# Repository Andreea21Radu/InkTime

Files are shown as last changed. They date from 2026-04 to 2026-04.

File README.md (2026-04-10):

# InkTime - Smartwatch PCB Design

**Autor:** Radu Andreea
**Licenta:** Apache License 2.0 

## 1. Arhitectura sistemului

Sistemul este construit in jurul microcontroller-ului **nRF52840**, care gestioneaza comunicatia si perifericele.

Structura generala este urmatoarea:

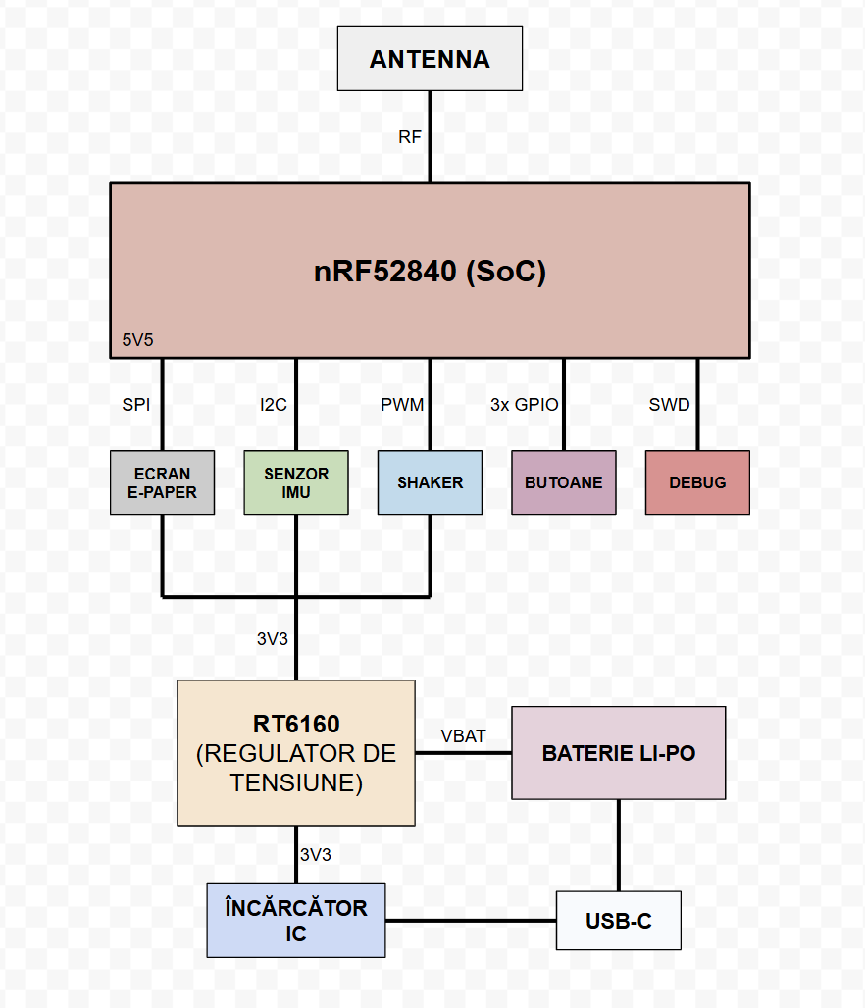
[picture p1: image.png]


## 2. BOM (Bill of Materials)

## CIRCUITE INTEGRATE (IC)

| Componentă | JLC Part # | Package | Descriere | Datasheet |
| :--- | :--- | :--- | :--- | :--- |
| IC1 | C3682423 | DSBGA-8 (1.6x1.1) | Încărcător baterie Li-Ion / Li-Polymer | [datasheet](https://www.ti.com/cn/lit/ds/symlink/bq25180.pdf) |
| IC2 | C81079 | DSBGA-9 | Driver haptic ERM/LRA | [datasheet](https://www.ti.com/cn/lit/gpn/drv2605) |
| IC3 | C189517 | LGA-12 (2x2) | Accelerometru 3 axe low-g 12bit | [datasheet](https://www.lcsc.com/datasheet/C189517.pdf) |
| IC9 | C7065276 | WLCSP-15B (2.3x1.4) | DC-DC buck-boost regulator I2C | [datasheet](https://wmsc.lcsc.com/wmsc/upload/file/pdf/v2/lcsc/2312271436_Richtek-Tech-RT6160AWSC_C7065276.pdf) |
| U1 | C3606653 | QFN-48 (6x6) | nRF52840 MCU | [datasheet](https://www.lcsc.com/datasheet/C3606653.pdf) |
| U2 | C2682616 | DFN-8-EP (2x2) | Fuel gauge baterie Li-Ion I2C | [datasheet](https://www.lcsc.com/datasheet/lcsc_datasheet_2410121738_Analog-Devices-Inc--Maxim-Integrated-MAX17048G-T10_C2682616.pdf) |

---

## CONECTORI

| Componentă | JLC Part # | Package | Descriere | Datasheet |
| :--- | :--- | :--- | :--- | :--- |
| J1 | C122434 | SMD, FFC/FPC 0.5mm | Conector FPC 24 pini, unghi drept | [datasheet](https://www.molex.com/content/dam/molex/molex-dot-com/products/automated/en-us/salesdrawingpdf/503/503480/5034802400_sd.pdf) |
| J2 | C90533 | 1mm pitch | Adaptor cablu 6 poziții | [datasheet](https://wmsc.lcsc.com/wmsc/upload/file/pdf/v2/lcsc/1810141506_LX-FFC6P1-0mm7CM_C90533.pdf) |
| J4 | C709357 | USB-C SMD | Conector USB Type-C 16P | [datasheet](https://www.lcsc.com/datasheet/lcsc_datasheet_2404191039_Shenzhen-Kinghelm-Elec-KH-TYPE-C-16P_C709357.pdf) |

---

## SEMICONDUCTORI

| Componentă | JLC Part # | Package | Descriere | Datasheet |
| :--- | :--- | :--- | :--- | :--- |
| Q1 | C2564 | TO-220AB | MOSFET P-channel 55V 74A | [datasheet](https://www.lcsc.com/datasheet/lcsc_datasheet_1809041724_Infineon-Technologies-IRF4905PBF_C2564.pdf) |
| Q3 | C469327 | SOT-323 | MOSFET N-channel 30V 1.5A | [datasheet](https://www.lcsc.com/datasheet/lcsc_datasheet_1912202016_Vishay-Intertech-SI1308EDL-T1-GE3_C469327.pdf) |
| D2, D4, D5 | C82046 | SOD-123 | Diodă Schottky 0.5A 30V | [datasheet](https://www.lcsc.com/datasheet/lcsc_datasheet_2304140030_onsemi-MBR0530T1G_C82046.pdf) |
| D3 | C2969755 | SOT-23-6L | Protecție ESD USB | [datasheet](https://wmsc.lcsc.com/wmsc/upload/file/pdf/v2/lcsc/2211080730_STMicroelectronics-USBLC6-2SC6Y_C2969755.pdf) |

---

## INDUCTORI

| Componentă | JLC Part # | Package | Descriere | Datasheet |
| :--- | :--- | :--- | :--- | :--- |
| L1, L2, L3 | C12669 | 0402 | Inductor general (chip inductor) | [datasheet](https://www.lcsc.com/datasheet/lcsc_datasheet_2304140030_Murata-Electronics-LQG15HS27NJ02D_C12669.pdf) |
| L5 | C1329646 | SMD 4.8x4.8mm | Power inductor 4.7µH 1.6A | [datasheet](https://wmsc.lcsc.com/wmsc/upload/file/pdf/v2/lcsc/2304140030_BOURNS-SRR4828A-4R7Y_C1329646.pdf) |
| L7 | C5832368 | 1008 | Power inductor 470nH 6.5A | [datasheet](https://wmsc.lcsc.com/wmsc/upload/file/pdf/v2/lcsc/2306021632_cjiang--Changjiang-Microelectronics-Tech-FTC252012SR47MBCA_C5832368.pdf) |

---

## CRISTALE

| Componentă | JLC Part # | Package | Descriere | Datasheet |
| :--- | :--- | :--- | :--- | :--- |
| X1 | C9009 | SMD3225-4P | Cristal Oscilator 32 MHz | [datasheet](https://www.lcsc.com/datasheet/lcsc_datasheet_2403291504_YXC-Crystal-Oscillators-X322532MOB4SI_C9009.pdf) |
| X2 | C32346 | SMD3215-2P | Cristal Oscilator 32.768 kHz | [datasheet](https://www.lcsc.com/datasheet/lcsc_datasheet_2404180925_Seiko-Epson-Q13FC13500004_C32346.pdf) |

---

## REZISTOARE

| Componentă | JLC Part # | Package | Descriere | Datasheet |
| :--- | :--- | :--- | :--- | :--- |
| R1_EP_DR | C3920633 | 0201 | 7.68kΩ Thin Film ±0.5% | [datasheet](https://wmsc.lcsc.com/wmsc/upload/file/pdf/v2/lcsc/2404081048_TE-Connectivity-CPF0201B511RE1_C3920633.pdf) |
| R1_USB, R2_USB | C3920633 | 0201 | 7.68kΩ Thin Film ±0.5% | [datasheet](https://wmsc.lcsc.com/wmsc/upload/file/pdf/v2/lcsc/2404081048_TE-Connectivity-CPF0201B511RE1_C3920633.pdf) |
| R2, R3, R4 | C3920633 | 0201 | 7.68kΩ Thin Film ±0.5% | [datasheet](https://wmsc.lcsc.com/wmsc/upload/file/pdf/v2/lcsc/2404081048_TE-Connectivity-CPF0201B511RE1_C3920633.pdf) |
| R2_EP_DR, R9, R_PWR_EPD | C3920633 | 0201 | 7.68kΩ Thin Film ±0.5% | [datasheet](https://wmsc.lcsc.com/wmsc/upload/file/pdf/v2/lcsc/2404081048_TE-Connectivity-CPF0201B511RE1_C3920633.pdf) |
| R5, R7, R8 | C3920633 | 0201 | 7.68kΩ Thin Film ±0.5% | [datasheet](https://wmsc.lcsc.com/wmsc/upload/file/pdf/v2/lcsc/2404081048_TE-Connectivity-CPF0201B511RE1_C3920633.pdf) |
| R17, R18 | C3920633 | 0201 | 7.68kΩ Thin Film ±0.5% | [datasheet](https://wmsc.lcsc.com/wmsc/upload/file/pdf/v2/lcsc/2404081048_TE-Connectivity-CPF0201B511RE1_C3920633.pdf) |
| R_TYPE_SEL | C3920633 | 0201 | 7.68kΩ Thin Film ±0.5% | [datasheet](https://wmsc.lcsc.com/wmsc/upload/file/pdf/v2/lcsc/2404081048_TE-Connectivity-CPF0201B511RE1_C3920633.pdf) |

---

## CAPACITORI

| Componentă | JLC Part # | Package | Descriere | Datasheet |
| :--- | :--- | :--- | :--- | :--- |
| C1, C2, C17, C18 | C9900156064 | 0201 | Generic chip capacitor | [datasheet](https://ds.yuden.co.jp/TYCOMPAS/or/download?pn=MLAST063SCG681JFNA01&fileType=CA) |
| C1-EP-DR | C9900156064 | 0201 | Generic chip capacitor | [datasheet](https://ds.yuden.co.jp/TYCOMPAS/or/download?pn=MLAST063SCG681JFNA01&fileType=CA) |
| C2-EP-DR | C9900156064 | 0201 | Generic chip capacitor | [datasheet](https://ds.yuden.co.jp/TYCOMPAS/or/download?pn=MLAST063SCG681JFNA01&fileType=CA) |
| C3, C4 | C9900156064 | 0201 | Generic chip capacitor | [datasheet](https://ds.yuden.co.jp/TYCOMPAS/or/download?pn=MLAST063SCG681JFNA01&fileType=CA) |
| C5, C7, C8, C12, C19 | C9900156064 | 0201 | Generic chip capacitor | [datasheet](https://ds.yuden.co.jp/TYCOMPAS/or/download?pn=MLAST063SCG681JFNA01&fileType=CA) |
| C6, C14, C20, C21 | C9900156064 | 0201 | Generic chip capacitor | [datasheet](https://ds.yuden.co.jp/TYCOMPAS/or/download?pn=MLAST063SCG681JFNA01&fileType=CA) |
| C9 | C9900156064 | 0201 | Generic chip capacitor | [datasheet](https://ds.yuden.co.jp/TYCOMPAS/or/download?pn=MLAST063SCG681JFNA01&fileType=CA) |
| C10, C13, C22 | C9900156064 | 0201 | Generic chip capacitor | [datasheet](https://ds.yuden.co.jp/TYCOMPAS/or/download?pn=MLAST063SCG681JFNA01&fileType=CA) |
| C11 | C9900156064 | 0201 | Generic chip capacitor | [datasheet](https://ds.yuden.co.jp/TYCOMPAS/or/download?pn=MLAST063SCG681JFNA01&fileType=CA) |
| C15 | C9900156064 | 0201 | Generic chip capacitor | [datasheet](https://ds.yuden.co.jp/TYCOMPAS/or/download?pn=MLAST063SCG681JFNA01&fileType=CA) |
| C16 | C9900156064 | 0201 | Generic chip capacitor | [datasheet](https://ds.yuden.co.jp/TYCOMPAS/or/download?pn=MLAST063SCG681JFNA01&fileType=CA) |
| C23, C27, C34, C42 | C21012218 | 0402 | Capacitor ceramic | [datasheet](https://jlc-prod-smt.oss-eu-central-1.aliyuncs.com/smtDataManualFile/8603520985945550848-C21012218.pdf) |
| C24, C39 | C9900179830 | 0402 | Capacitor ceramic | N/A |
| C25, C33 | C9900179830 | 0402 | Capacitor ceramic | N/A |
| C29, C30, C31, C32, C37, C38 | C3920633 | 0201 | Capacitor ceramic | [datasheet](https://ds.yuden.co.jp/TYCOMPAS/or/download?pn=MLAST063SCG681JFNA01&fileType=CA) |
| C43 | C9900156064 | 0201 | Generic chip capacitor | [datasheet](https://ds.yuden.co.jp/TYCOMPAS/or/download?pn=MLAST063SCG681JFNA01&fileType=CA) |
| EPD_C1, EPD_C2, EPD_C6, EPD_C7, EPD_C8, EPD_C9, EPD_C10, EPD_C11, EPD_C12 | C9900156064 | 0201 | Generic chip capacitor | [datasheet](https://ds.yuden.co.jp/TYCOMPAS/or/download?pn=MLAST063SCG681JFNA01&fileType=CA) |
| EPD_C5 | C9900156064 | 0201 | Generic chip capacitor | [datasheet](https://ds.yuden.co.jp/TYCOMPAS/or/download?pn=MLAST063SCG681JFNA01&fileType=CA) |

---

## ALTE COMPONENTE

| Componentă | JLC Part # | Package | Descriere | Datasheet |
| :--- | :--- | :--- | :--- | :--- |
| ANT1 | C2917717 | 1206 | Antenă Patch 2.4 GHz | [datasheet](https://www.lcsc.com/datasheet/lcsc_datasheet_2404021210_Johanson-Dielectrics-2450AT18B100E_C2917717.pdf) |
| SJ1 | N/A | Solder Jumper | SMD solder JUMPER (leave open) | N/A |
| SW_DN, SW_ENT, SW_UP | C569760 | SMD 3.9x2.9mm | Buton tactil SPST (Tactile Switch) | [datasheet](https://wmsc.lcsc.com/wmsc/upload/file/pdf/v2/lcsc/2301111010_PANASONIC-EVPAKE31A_C569760.pdf) |
| TP (Test Pads) | N/A | N/A | Puncte de testare (Test pads) | N/A |

## 3. Functionalitate hardware si specificatii tehnice

Proiectul **InkTime** reprezinta un dispozitiv wearable optimizat pentru consum redus de energie, capabil sa functioneze pe perioade lungi de timp datorita combinatiei dintre un microcontroller eficient si un display E-Ink, care consuma energie doar la actualizare.

---

### 3.1 Unitatea centrala (Microcontroller)

In centrul sistemului se afla circuitul **nRF52840**, care integreaza toate functiile principale:

* Procesor **ARM Cortex-M4F la 64 MHz**, suficient pentru procesare de semnale si control periferice
* Suport integrat pentru **Bluetooth Low Energy (BLE)**, utilizat pentru comunicarea cu telefonul
* Moduri de consum redus (sleep si deep sleep), unde curentul scade pana la nivel de microamperi

Acest microcontroller permite rularea simultana a comunicatiei wireless si a interactiunii cu senzorii, mentinand consumul scazut.

### 3.2 Sistem de alimentare

Alimentarea este realizata printr-un lant complet de power management:

* **BQ25180** – responsabil pentru incarcarea bateriei Li-Po prin USB-C, folosind metoda CC/CV si protectii integrate
* **RT6160** – convertor buck-boost care asigura o tensiune stabila de **3.3V**, chiar daca bateria scade sub aceasta valoare
* **MAX17048** – circuit de monitorizare a bateriei, care transmite starea de incarcare catre microcontroller prin I2C

Avantajul folosirii convertorului buck-boost este utilizarea eficienta a bateriei pe intreaga plaja de tensiuni.

### 3.3 Comunicatia intre module

Pentru conectarea componentelor, sistemul foloseste doua interfete principale:

#### Magistrala I2C

Este utilizata pentru perifericele inteligente:

* accelerometrul (IMU)
* fuel gauge-ul
* driverul haptic

Toate aceste componente sunt conectate pe aceeasi magistrala, ceea ce reduce numarul de pini folositi si simplifica traseele pe PCB.

#### Magistrala SPI

Este dedicata exclusiv display-ului:

* display-ul E-Ink este conectat prin SPI folosind conectorul FPC
* aceasta interfata permite transfer rapid de date necesar actualizarii imaginii

### 3.4 Interactiune cu utilizatorul

Dispozitivul include:

* 3 butoane pentru navigare (UP, ENTER, DOWN)
* feedback haptic realizat cu **DRV2605**, controlat prin PWM

Acest sistem permite interactiune intuitiva fara consum mare de energie.

### 3.5 Estimarea consumului de energie

Sistemul este alimentat de o baterie Li-Po de aproximativ **250 mAh**.

Consum estimat:

* Sleep (MCU + BLE): ~35 µA
* Functionare activa (citire senzori): ~120 µA
* Actualizare display: ~25 µA

Curent mediu total:

I_avg ≈ 180 µA = 0.18 mA

### 3.6 Autonomie estimata

Autonomia teoretica:

T = 250 mAh / 0.18 mA ≈ 1380 ore

In conditii reale (BLE, senzori, vibratii):

👉 aproximativ **9 – 14 zile**

## 4. Mapare pini nRF52840

### 4.1 Alocarea pinilor

| Componenta | Semnal | Pin nRF | Directie | Motiv |
| --- | --- | --- | --- | --- |
| Display E-Ink | SCK | P0.11 | Output | Clock SPI |
| Display E-Ink | MOSI | P0.12 | Output | Transfer date |
| Display E-Ink | CS | P0.13 | Output | Selectie dispozitiv  |
| Display E-Ink | DC | P0.14 | Output | Data / Command |
| Display E-Ink | RESET  | P0.15 | Output | Reset hardware |
| Display E-Ink | BUSY | P0.16 | Input | Status display |
| I2C | SDA | P0.26 | I/O | Linie date |
| I2C | SCL | P0.27 | Output | Linie clock |
| Buton UP | GPIO | P1.07 | Input | Navigare |
| Buton ENTER | GPIO | P1.08 | Input | Confirmare |
| Buton DOWN | GPIO | P1.09 | Input | Navigare |
| Motor haptic  | PWM | P1.02 | Output | Control vibratii |
| RT6160 | EN | P0.18 | Output | Activare convertor |
| IMU | INT | P0.25 | Input | Intrerupere hardware |

---

### 4.2 Decizii de design

* **Port 0** a fost folosit pentru interfete rapide (SPI, I2C)
* **Port 1** a fost folosit pentru butoane, pentru a evita interferente
* pinii SPI au fost grupati fizic pentru trasee mai scurte
* magistrala I2C este comuna pentru mai multe dispozitive → economie de pini
* pinii NFC (P0.09, P0.10) au fost evitati pentru extensii viitoare

## 5. Design log si decizii de implementare

### 5.1 Layout PCB

* componentele au fost plasate compact
* traseele de alimentare au fost facute la **0.3 mm**
* traseele de semnal la **0.15 mm**
* zona antenei a fost lasata fara cupru

### 5.2 Probleme si solutii

* componente 0201 → necesare pentru spatiu redus
* routing dificil sub MCU → s-au folosit trasee mai subtiri local
* antena → zona keep-out pentru performanta RF

### 5.3 Integritate semnal

* condensatori de decuplare (100nF) plasati foarte aproape de pini
* GND realizat cu polygon pour pe ambele straturi
* via stitching pentru masa

## 6. Randari si imagini

(Imaginile se gasesc in folderul `Images`)

* vedere PCB top
* vedere PCB bottom
* randare 3D
* vedere explodata

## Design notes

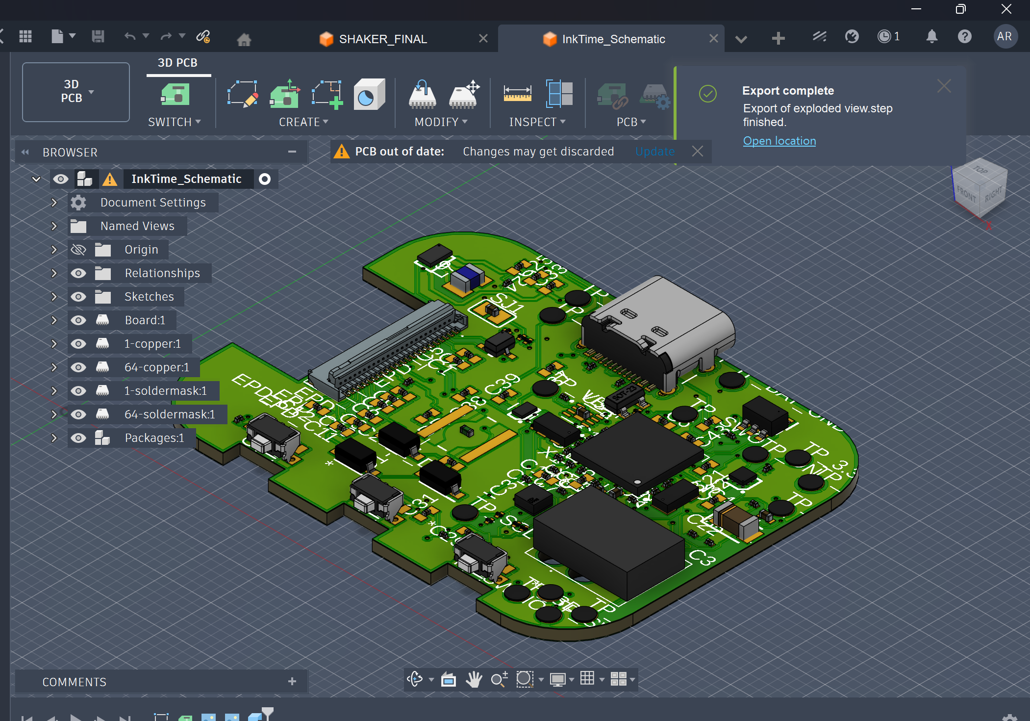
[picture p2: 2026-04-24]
Images/3d.png

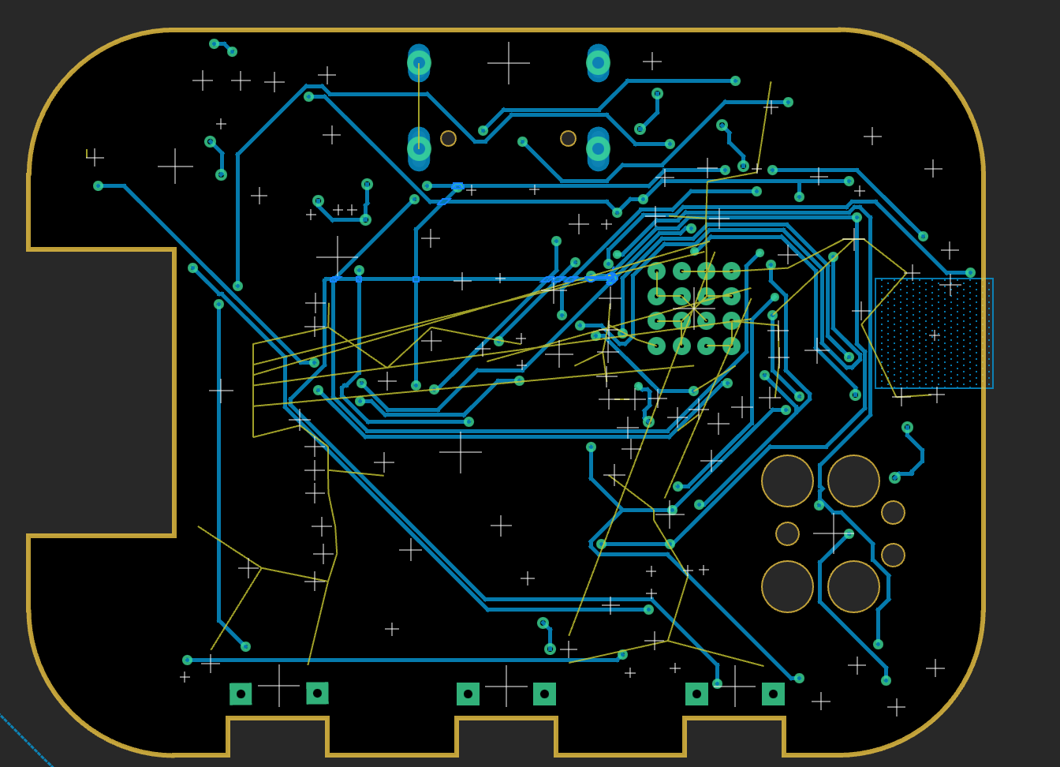
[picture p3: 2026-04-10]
Images/pcb_bottom.png

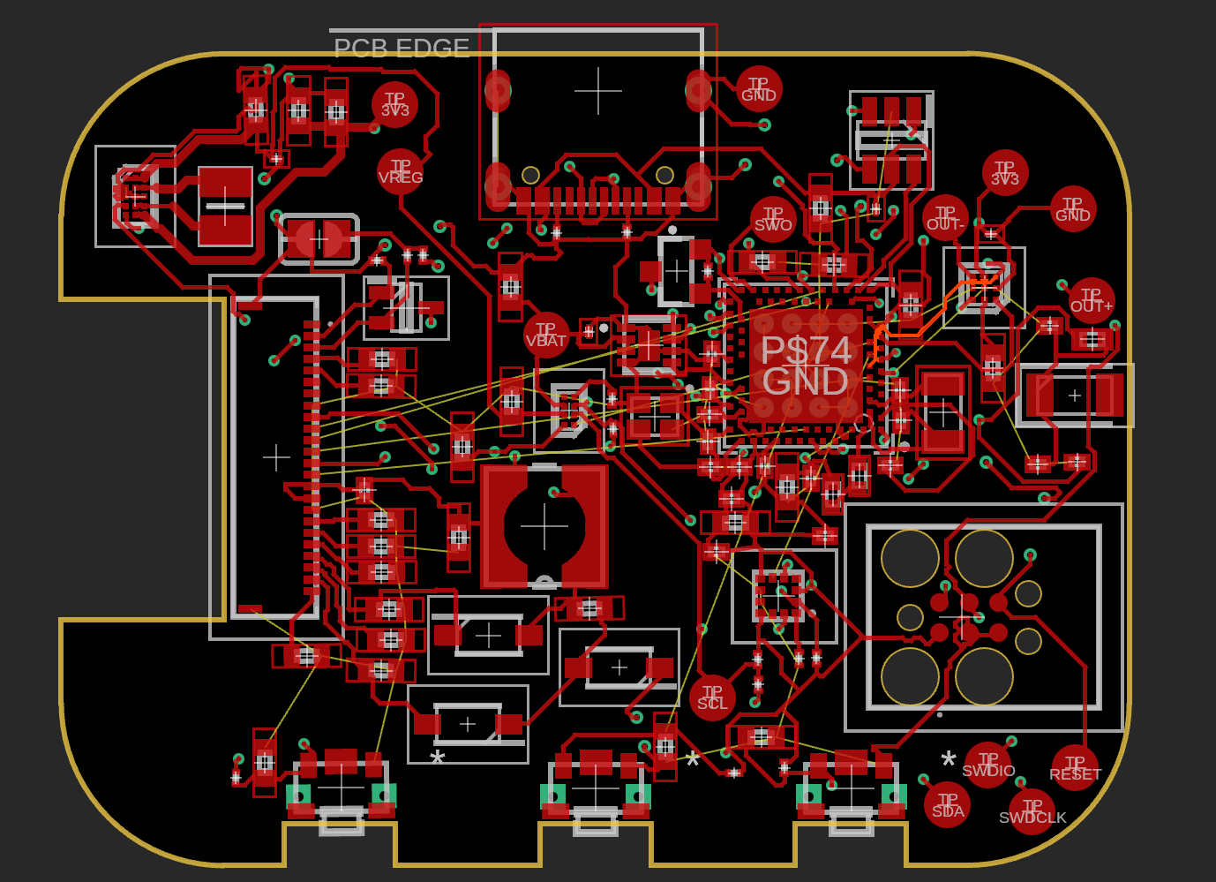
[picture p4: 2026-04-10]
Images/pcb_top.png

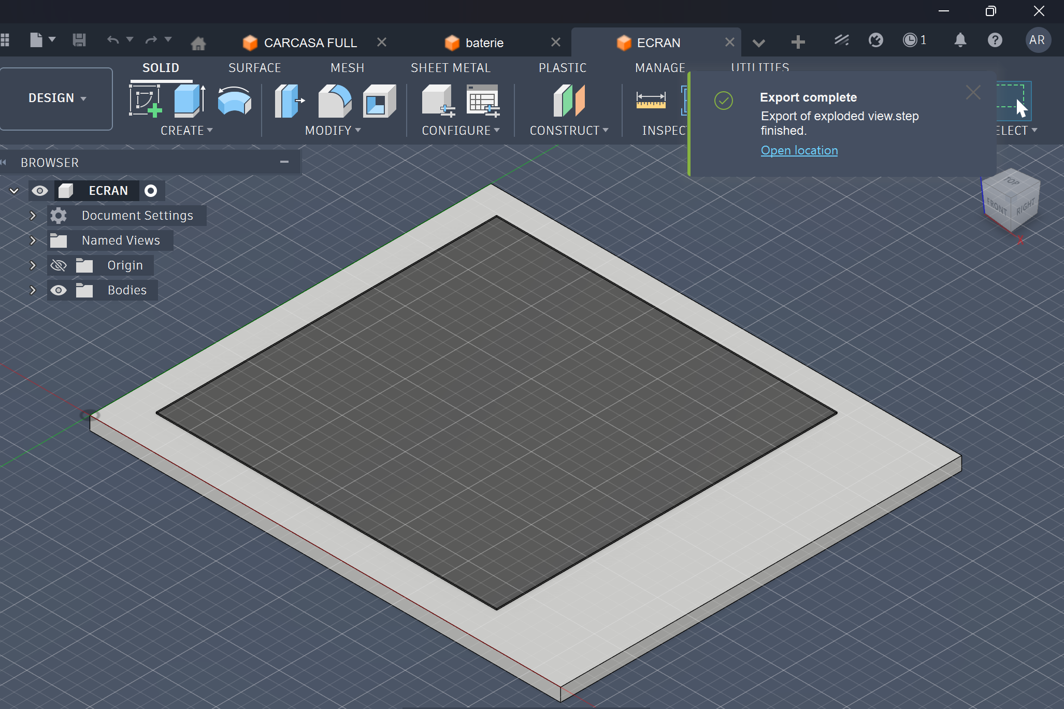
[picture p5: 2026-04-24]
Images/ecran.png

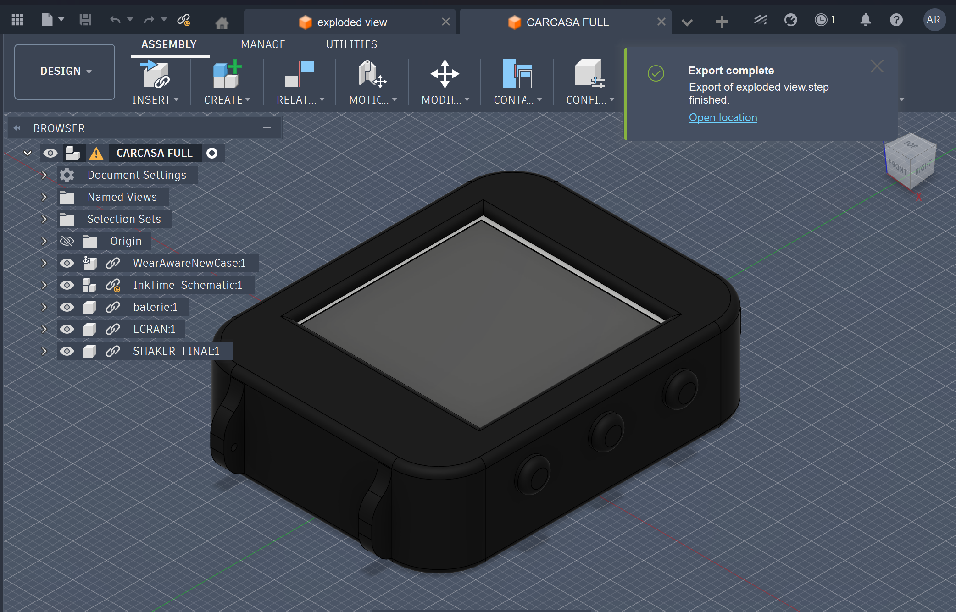
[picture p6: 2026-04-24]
Images/carcasa_full.png

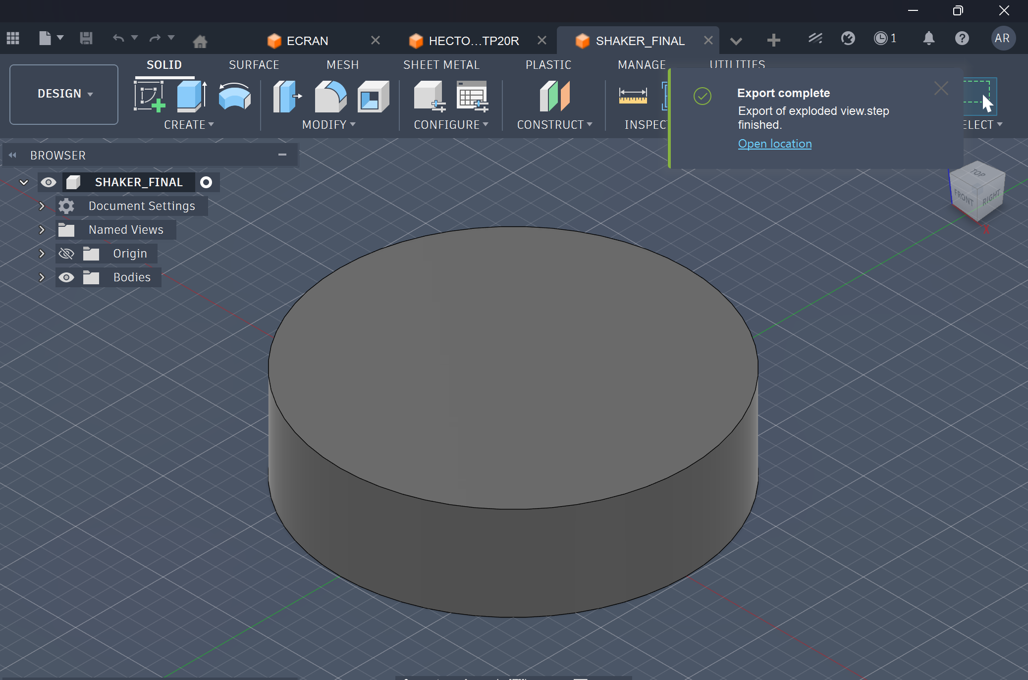
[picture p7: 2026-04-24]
Images/shaker.png

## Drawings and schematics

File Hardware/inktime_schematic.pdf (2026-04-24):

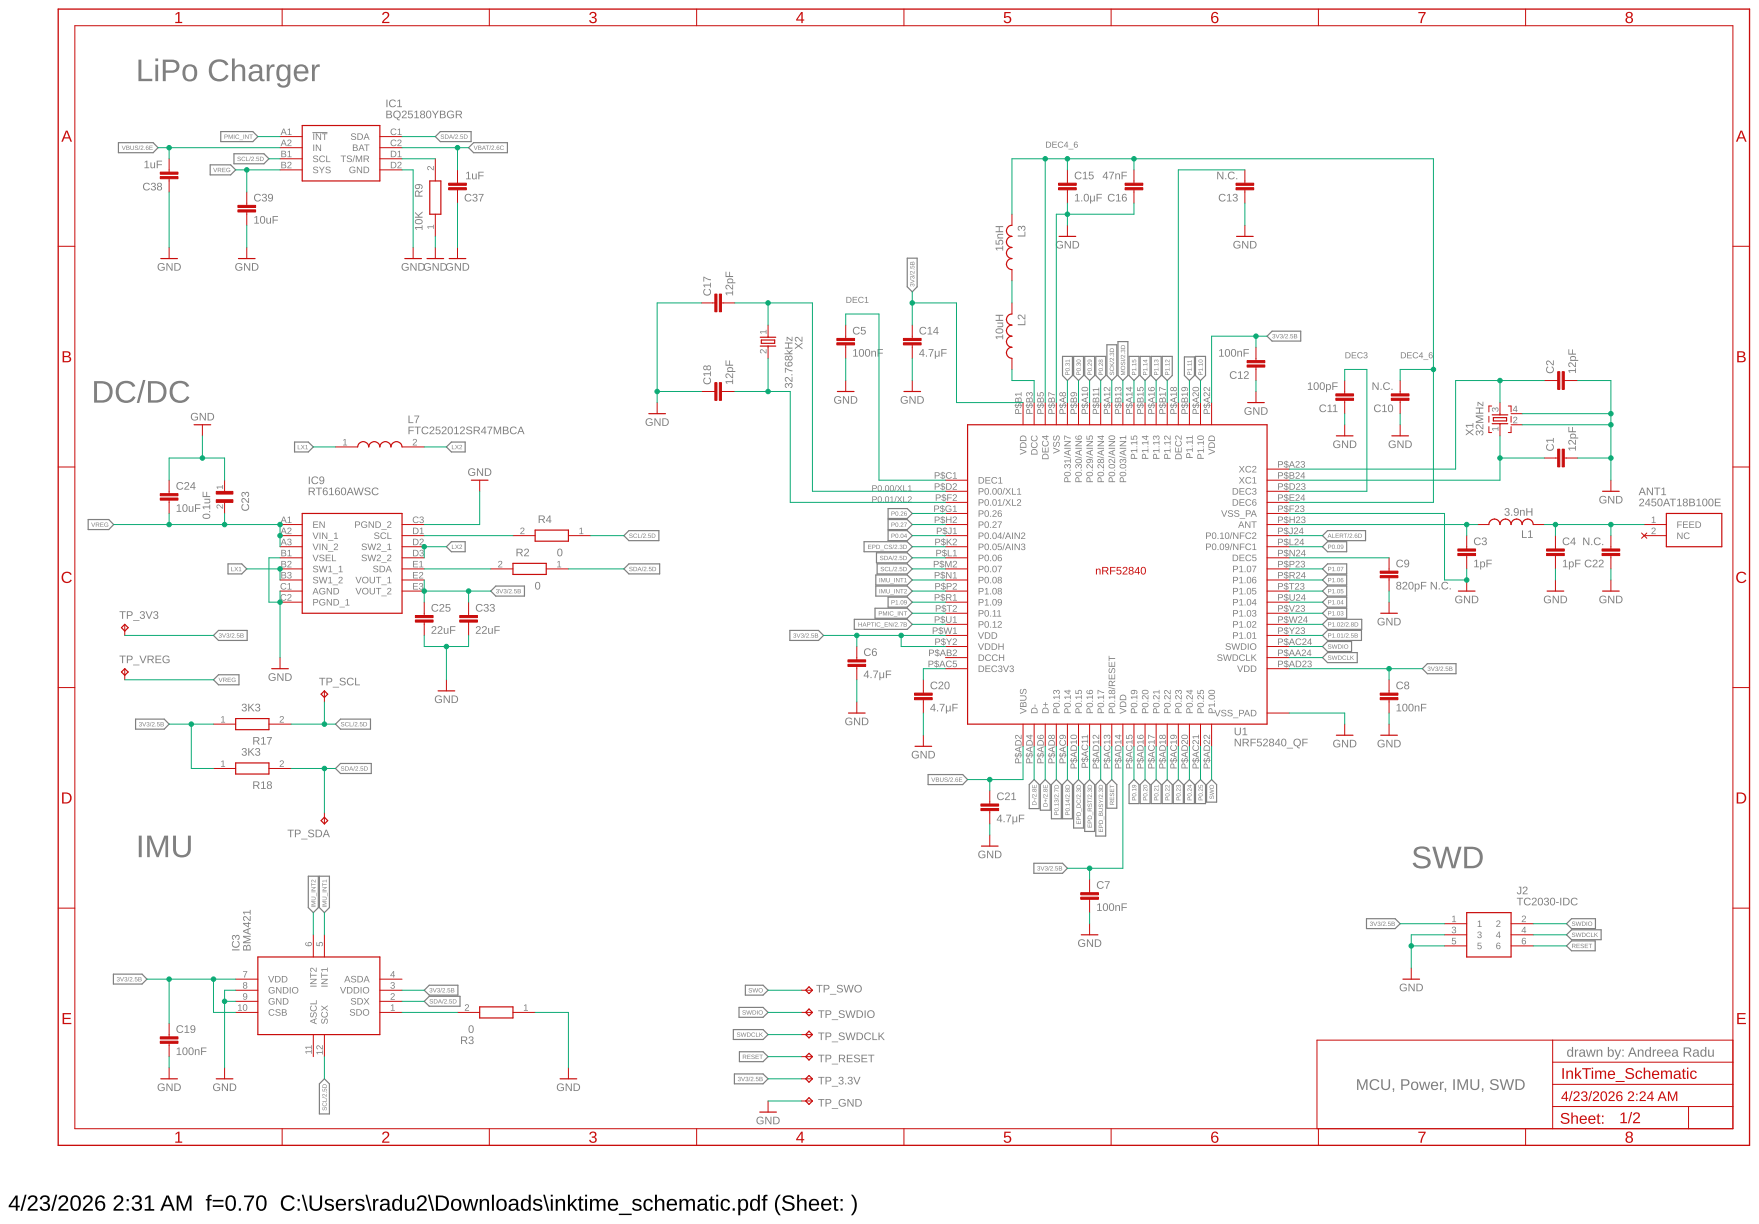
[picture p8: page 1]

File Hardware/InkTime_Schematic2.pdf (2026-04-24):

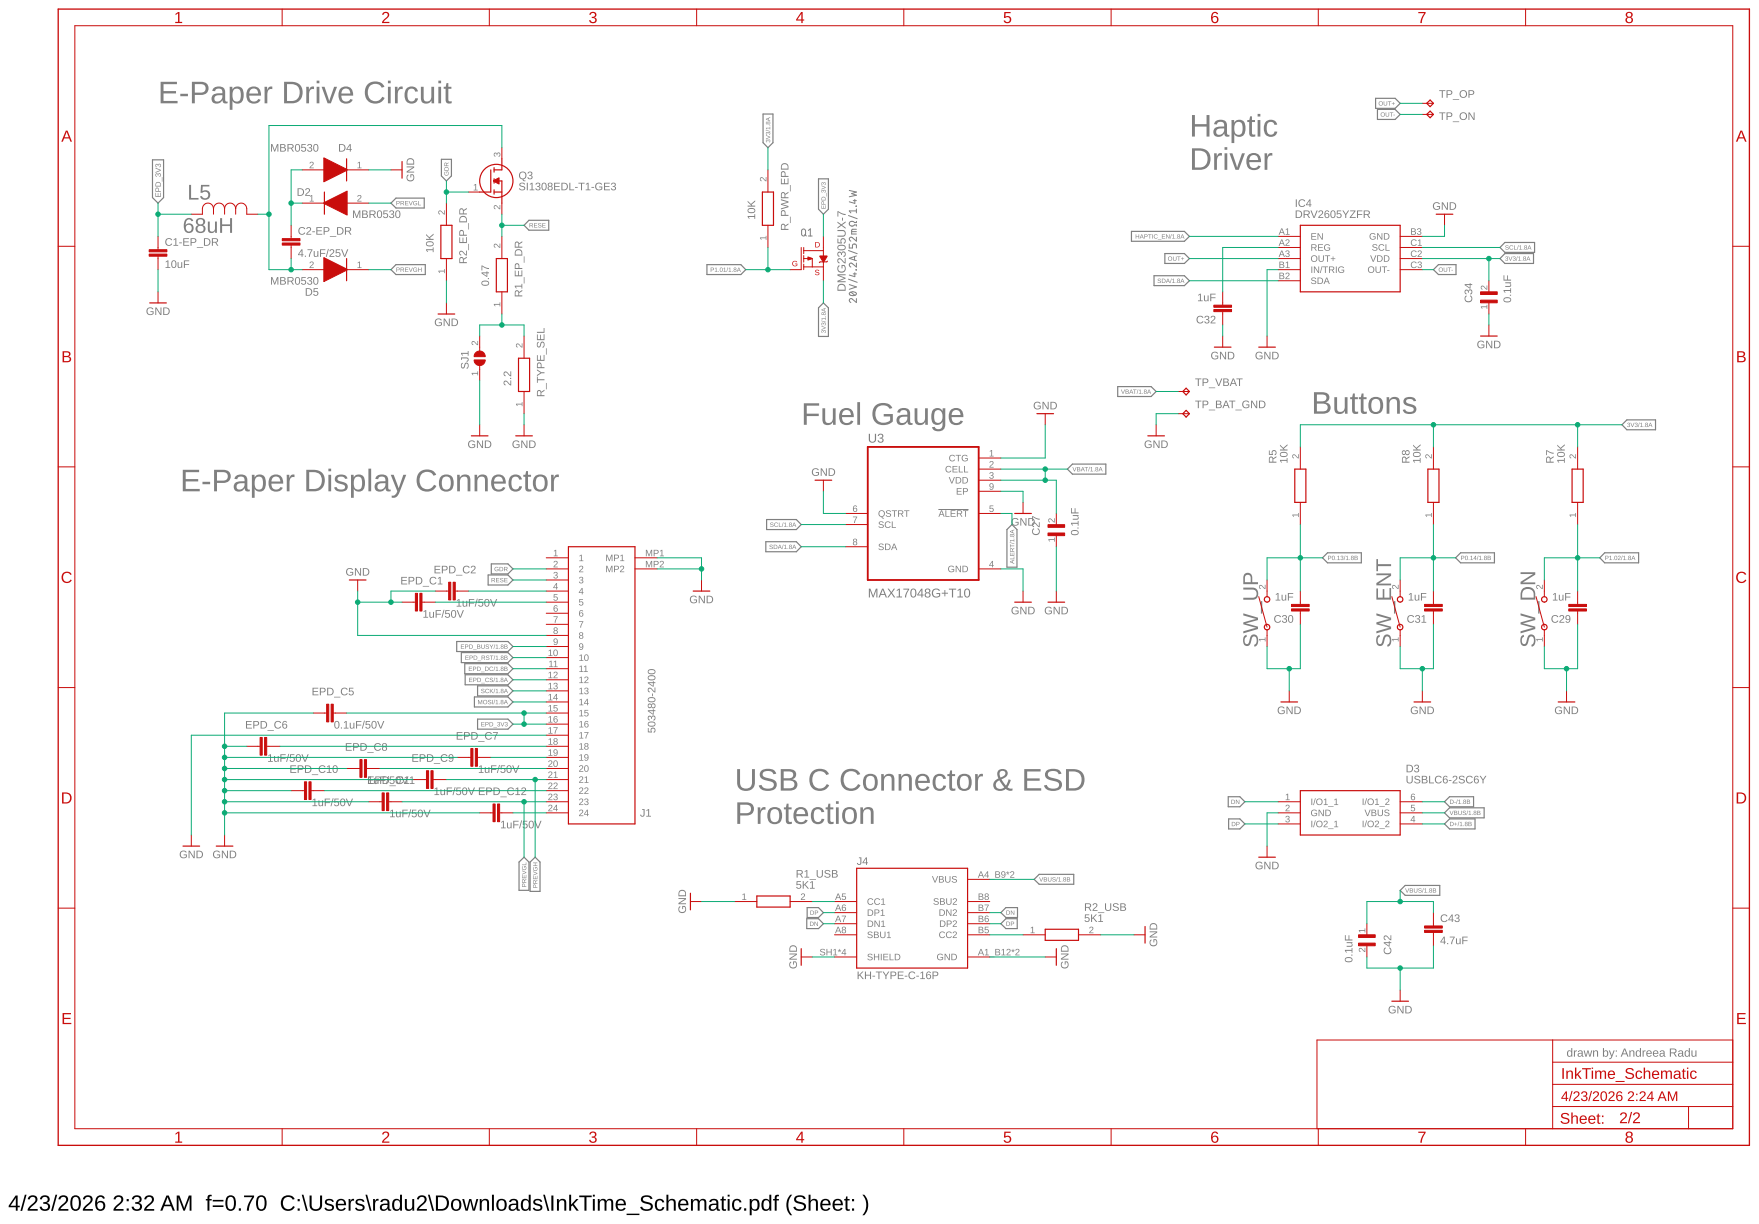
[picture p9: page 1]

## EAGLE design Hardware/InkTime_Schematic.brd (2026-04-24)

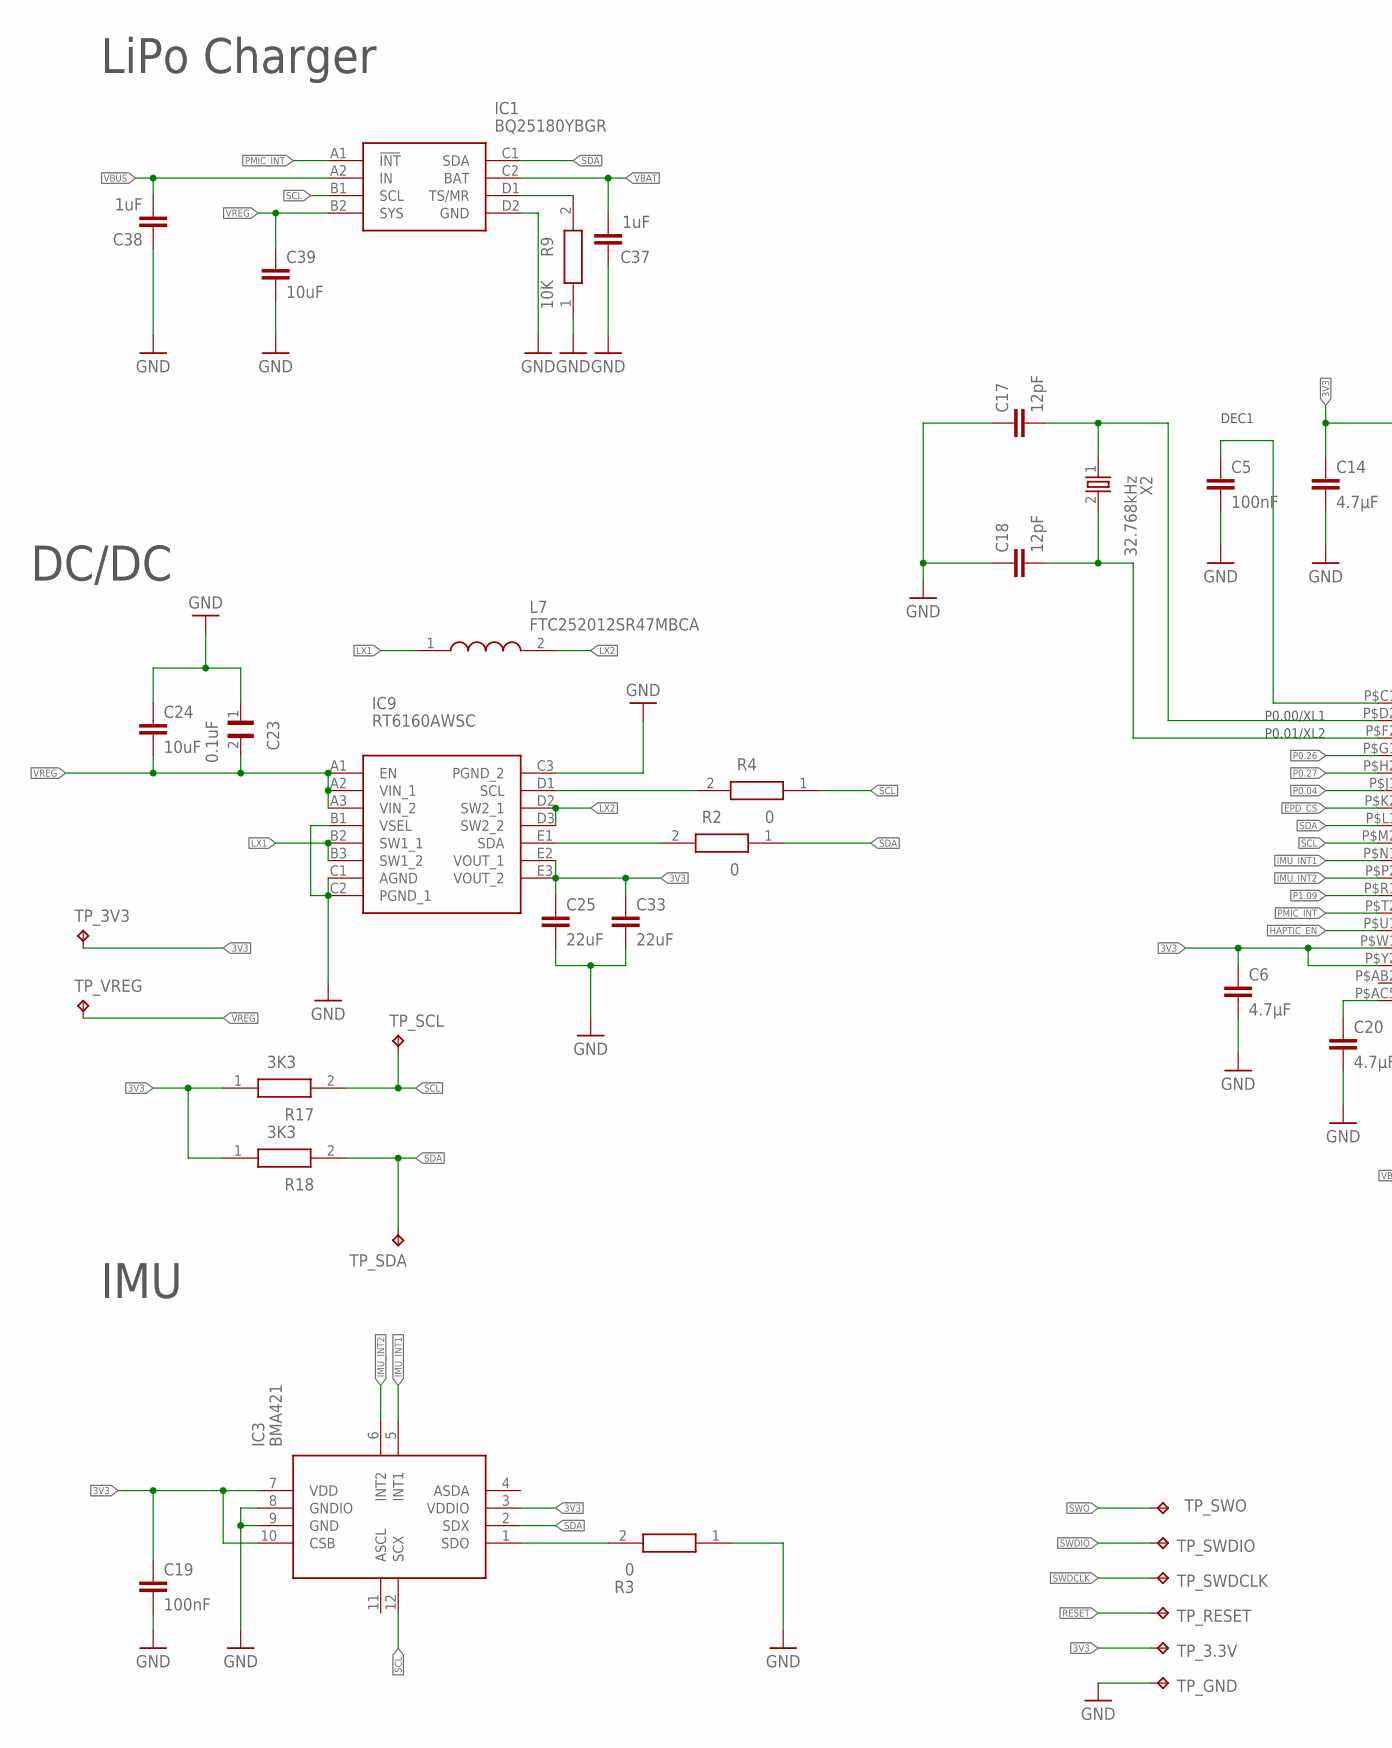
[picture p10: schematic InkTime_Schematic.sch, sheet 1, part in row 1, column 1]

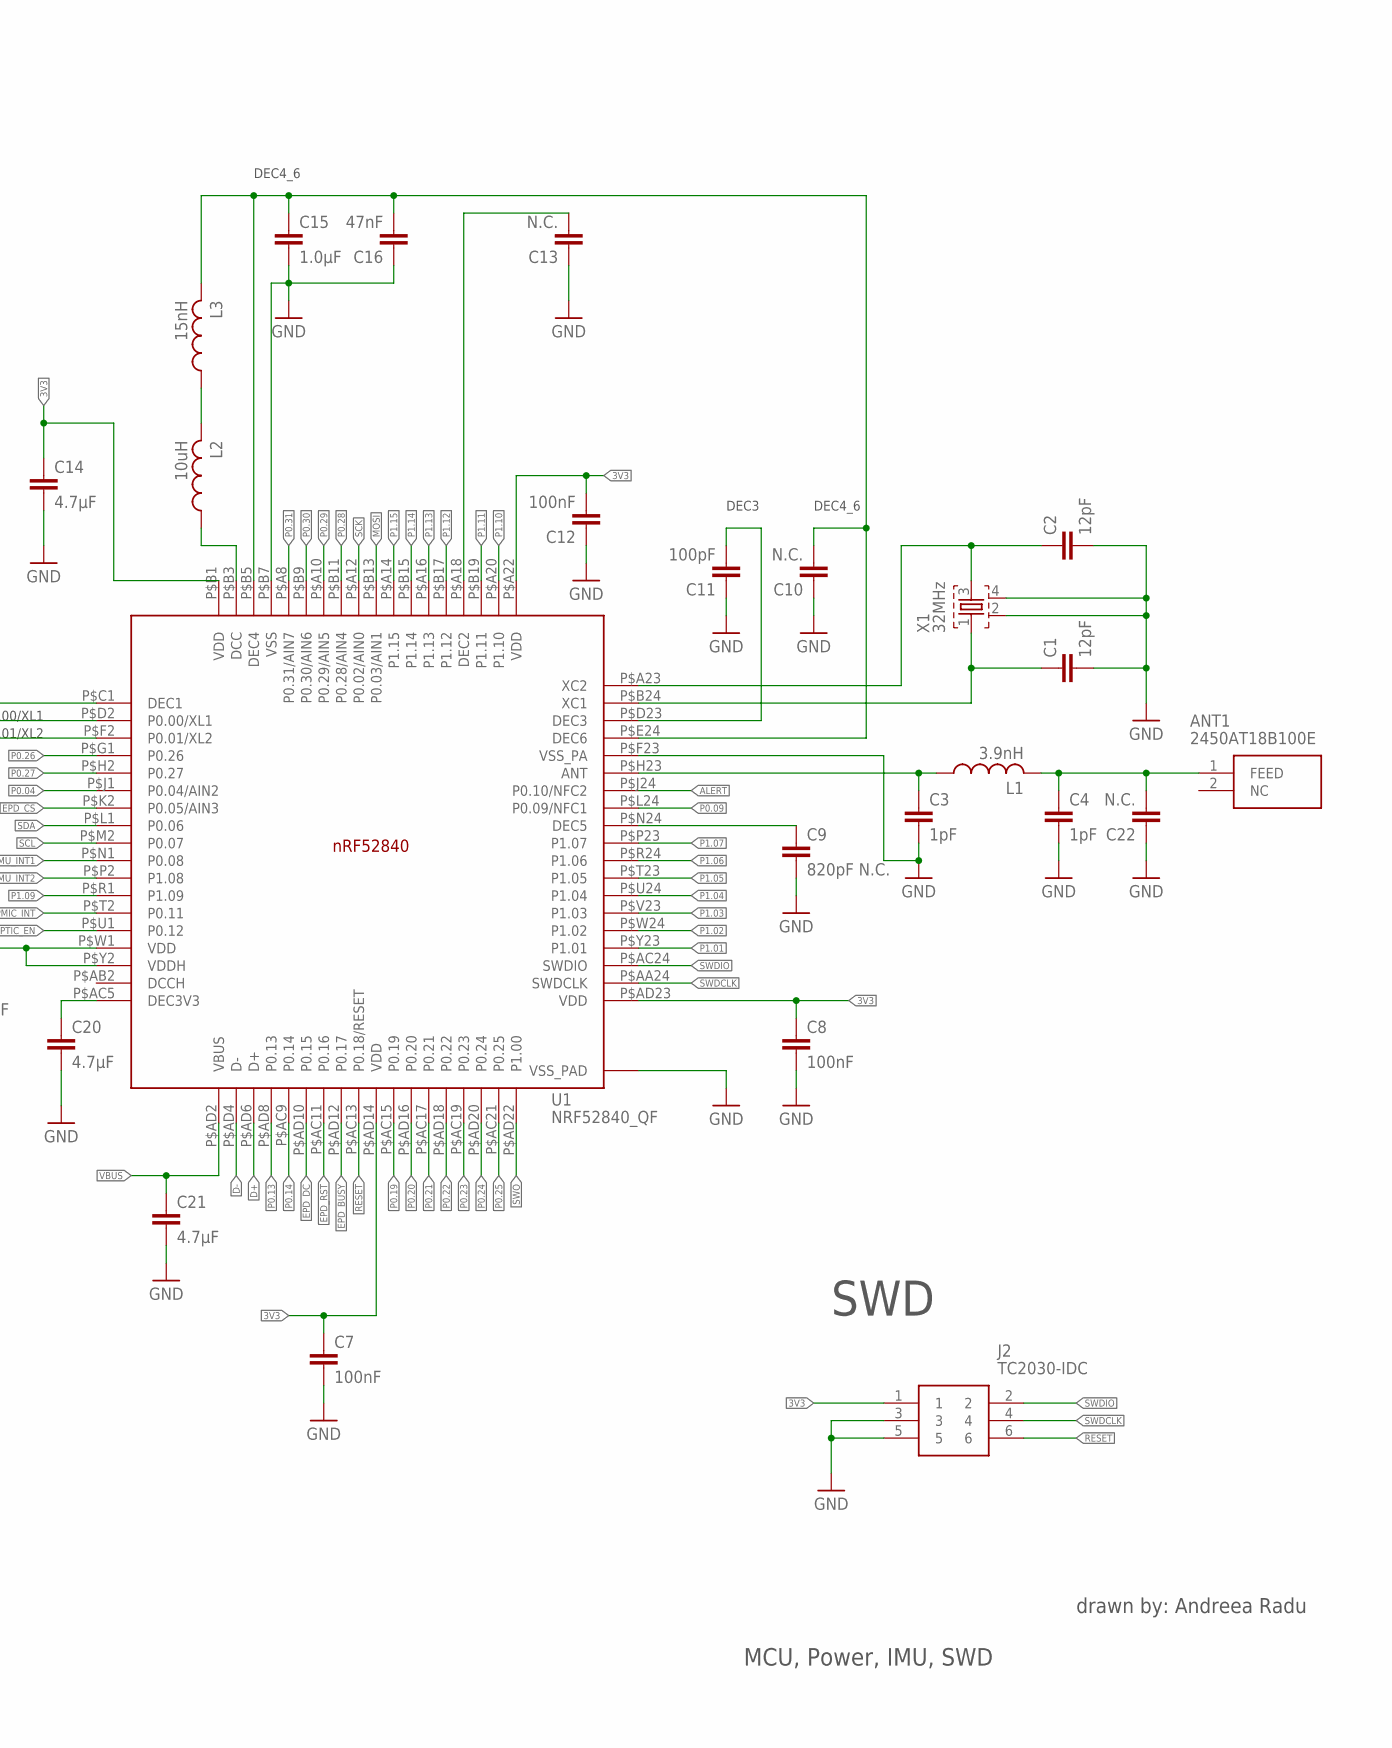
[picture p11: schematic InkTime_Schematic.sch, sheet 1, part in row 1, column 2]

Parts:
ANT1: 2450AT18B100E; 2450AT18B100E_ANTC3216X140N
C1, C2, C17, C18: 12pF; NORDIC_NRF_3_RESC0201_L
C3, C4: 1pF; NORDIC_NRF_3_RESC0201_L
C5, C7, C8, C12, C19: 100nF; NORDIC_NRF_3_RESC0201_L
C6, C14, C20, C21: 4.7μF; ESP32_C6_LIBRARY_1_ESP32_WROVER_EAGLE-LTSPICE_C0402
C9: 820pF N.C.; NORDIC_NRF_3_RESC0201_L
C10, C13, C22: N.C.; NORDIC_NRF_3_RESC0201_L
C11: 100pF; NORDIC_NRF_3_RESC0201_L
C15: 1.0μF; ESP32_C6_LIBRARY_1_ESP32_WROVER_EAGLE-LTSPICE_C0402
C16: 47nF; NORDIC_NRF_3_RESC0201_L
C23: 0.1uF; GRM011R60J152KE01L_2_CAPC0201X13N
C24, C39: 10uF; ESP32_C6_LIBRARY_1_ESP32_WROVER_EAGLE-LTSPICE_C0402
C25, C33: 22uF; ESP32_C6_LIBRARY_1_ESP32_WROVER_EAGLE-LTSPICE_C0402
C37, C38: 1uF; ESP32_C6_LIBRARY_1_ESP32_WROVER_EAGLE-LTSPICE_C0402
IC1: BQ25180YBGR; BQ25180YBGR_BGA8C40P2X4_100X155X50
IC3: BMA421; BMA423_BMA423
IC9: RT6160AWSC; RT6160AWSC_BGA15C40P3X5_140X230X60
J2: TC2030-IDC; TC2030-IDC_TC2030IDC
L1: 3.9nH; NORDIC_NRF_2_RESC0402_L
L2: 10uH; NORDIC_NRF_2_RESC0402_L
L3: 15nH; NORDIC_NRF_2_RESC0402_L
L7: FTC252012SR47MBCA; MLP2016SR47MT0S1_INDC2016X100N
R2, R3, R4: 0; CPF0201D7K68C1_0201
R9: 10K; CPF0201D7K68C1_0201
R17, R18: 3K3; CPF0201D7K68C1_0201
TP_3.3V, TP_3V3: HECTOR_WATCH_1_TPTP20R; HECTOR_WATCH_1_TP20R
TP_GND: HECTOR_WATCH_1_TPTP20R; HECTOR_WATCH_1_TP20R
TP_RESET: HECTOR_WATCH_1_TPTP20R; HECTOR_WATCH_1_TP20R
TP_SCL: HECTOR_WATCH_1_TPTP20R; HECTOR_WATCH_1_TP20R
TP_SDA: HECTOR_WATCH_1_TPTP20R; HECTOR_WATCH_1_TP20R
TP_SWDCLK: HECTOR_WATCH_1_TPTP20R; HECTOR_WATCH_1_TP20R
TP_SWDIO: HECTOR_WATCH_1_TPTP20R; HECTOR_WATCH_1_TP20R
TP_SWO: HECTOR_WATCH_1_TPTP20R; HECTOR_WATCH_1_TP20R
TP_VREG: HECTOR_WATCH_1_TPTP20R; HECTOR_WATCH_1_TP20R
U1: NRF52840_QF; NORDIC_NRF_4_AQFN50P700X700X85_HS-74N
X1: 32MHz; NORDIC_NRF_BT-XTAL_2016_N
X2: 32.768kHz; NORDIC_NRF_1_XTAL_3215_N

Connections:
3V3: C6.1, C7.1, C8.1, C12.2, C14.1, C19.1, C25.1, C33.1, IC3.3 (VDDIO), IC3.7 (VDD), IC3.10 (CSB), IC9.E2 (VOUT_1), IC9.E3 (VOUT_2), J2.1, R17.1, R18.1, TP_3.3V.TP, TP_3V3.TP, U1.P$A22 (VDD), U1.P$AD14 (VDD), U1.P$AD23 (VDD), U1.P$B1 (VDD), U1.P$W1 (VDD), U1.P$Y2 (VDDH); also elsewhere on the board
ALERT: U1.P$J24 (P0.10/NFC2); also elsewhere on the board
D+: U1.P$AD6 (D+); also elsewhere on the board
D-: U1.P$AD4 (D-); also elsewhere on the board
EPD_BUSY: U1.P$AD12 (P0.17); also elsewhere on the board
EPD_CS: U1.P$K2 (P0.05/AIN3); also elsewhere on the board
EPD_DC: U1.P$AD10 (P0.15); also elsewhere on the board
EPD_RST: U1.P$AC11 (P0.16); also elsewhere on the board
GND: C1.2, C2.2, C3.2, C4.2, C5.2, C6.2, C7.2, C8.2, C9.2, C10.1, C11.1, C12.1, C13.1, C14.2, C15.2, C16.1, C17.1, C18.1, C19.2, C20.2, C21.2, C22.1, C23.1, C24.1, C25.2, C33.2, C37.1, C38.1, C39.2, IC1.D2 (GND), IC3.8 (GNDIO), IC3.9 (GND), IC9.B1 (VSEL), IC9.C1 (AGND), IC9.C2 (PGND_1), IC9.C3 (PGND_2), J2.3, J2.5, R3.1, R9.1, TP_GND.TP, U1.P$74 (VSS_PAD), U1.P$75 (VSS_PAD), U1.P$76 (VSS_PAD), U1.P$77 (VSS_PAD), U1.P$78 (VSS_PAD), U1.P$79 (VSS_PAD), U1.P$80 (VSS_PAD), U1.P$81 (VSS_PAD), U1.P$82 (VSS_PAD), U1.P$83 (VSS_PAD), U1.P$84 (VSS_PAD), U1.P$85 (VSS_PAD), U1.P$86 (VSS_PAD), U1.P$87 (VSS_PAD), U1.P$88 (VSS_PAD), U1.P$89 (VSS_PAD), U1.P$90 (VSS_PAD), U1.P$B7 (VSS), U1.P$F23 (VSS_PA), X1.2, X1.4; also elsewhere on the board
HAPTIC_EN: U1.P$U1 (P0.12); also elsewhere on the board
IMU_INT1: IC3.5 (INT1), U1.P$N1 (P0.08)
IMU_INT2: IC3.6 (INT2), U1.P$P2 (P1.08)
LX1: IC9.B2 (SW1_1), IC9.B3 (SW1_2), L7.1
LX2: IC9.D2 (SW2_1), IC9.D3 (SW2_2), L7.2
MOSI: U1.P$B13 (P0.03/AIN1); also elsewhere on the board
unnamed: C5.1, U1.P$C1 (DEC1)
unnamed: IC1.D1 (TS/MR), R9.2
unnamed: IC9.D1 (SCL), R4.2
unnamed: IC9.E1 (SDA), R2.2
unnamed: IC3.1 (SDO), R3.2
unnamed: C20.1, U1.P$AC5 (DEC3V3)
unnamed: C9.1, U1.P$N24 (DEC5)
unnamed: C3.1, L1.1, U1.P$H23 (ANT)
unnamed: ANT1.1 (FEED), C4.1, C22.2, L1.2
unnamed: L2.1, U1.P$B3 (DCC)
unnamed: L2.2, L3.1
unnamed: C10.2, C15.1, C16.2, L3.2, U1.P$B5 (DEC4), U1.P$E24 (DEC6)
unnamed: C13.2, U1.P$A18 (DEC2)
unnamed: C11.2, U1.P$D23 (DEC3)
unnamed: C2.1, U1.P$A23 (XC2), X1.3
unnamed: C1.1, U1.P$B24 (XC1), X1.1
unnamed: C17.2, U1.P$D2 (P0.00/XL1), X2.1
unnamed: C18.2, U1.P$F2 (P0.01/XL2), X2.2
P0.04: U1.P$J1 (P0.04/AIN2)
P0.09: U1.P$L24 (P0.09/NFC1)
P0.13: U1.P$AD8 (P0.13); also elsewhere on the board
P0.14: U1.P$AC9 (P0.14); also elsewhere on the board
P0.19: U1.P$AC15 (P0.19)
P0.20: U1.P$AD16 (P0.20)
P0.21: U1.P$AC17 (P0.21)
P0.22: U1.P$AD18 (P0.22)
P0.23: U1.P$AC19 (P0.23)
P0.24: U1.P$AD20 (P0.24)
P0.25: U1.P$AC21 (P0.25)
P0.26: U1.P$G1 (P0.26)
P0.27: U1.P$H2 (P0.27)
P0.28: U1.P$B11 (P0.28/AIN4)
P0.29: U1.P$A10 (P0.29/AIN5)
P0.30: U1.P$B9 (P0.30/AIN6)
P0.31: U1.P$A8 (P0.31/AIN7)
P1.01: U1.P$Y23 (P1.01); also elsewhere on the board
P1.02: U1.P$W24 (P1.02); also elsewhere on the board
P1.03: U1.P$V23 (P1.03)
P1.04: U1.P$U24 (P1.04)
P1.05: U1.P$T23 (P1.05)
P1.06: U1.P$R24 (P1.06)
P1.07: U1.P$P23 (P1.07)
P1.09: U1.P$R1 (P1.09)
P1.10: U1.P$A20 (P1.10)
P1.11: U1.P$B19 (P1.11)
P1.12: U1.P$B17 (P1.12)
P1.13: U1.P$A16 (P1.13)
P1.14: U1.P$B15 (P1.14)
P1.15: U1.P$A14 (P1.15)
PMIC_INT: IC1.A1 (!INT), U1.P$T2 (P0.11)
RESET: J2.6, TP_RESET.TP, U1.P$AC13 (P0.18/RESET)
SCK: U1.P$A12 (P0.02/AIN0); also elsewhere on the board
SCL: IC1.B1 (SCL), IC3.12 (SCX), R4.1, R17.2, TP_SCL.TP, U1.P$M2 (P0.07); also elsewhere on the board
SDA: IC1.C1 (SDA), IC3.2 (SDX), R2.1, R18.2, TP_SDA.TP, U1.P$L1 (P0.06); also elsewhere on the board
SWDCLK: J2.4, TP_SWDCLK.TP, U1.P$AA24 (SWDCLK)
SWDIO: J2.2, TP_SWDIO.TP, U1.P$AC24 (SWDIO)
SWO: TP_SWO.TP, U1.P$AD22 (P1.00)
VBAT: C37.2, IC1.C2 (BAT); also elsewhere on the board
VBUS: C21.1, C38.2, IC1.A2 (IN), U1.P$AD2 (VBUS); also elsewhere on the board
VREG: C23.2, C24.2, C39.1, IC1.B2 (SYS), IC9.A1 (EN), IC9.A2 (VIN_1), IC9.A3 (VIN_2), TP_VREG.TP

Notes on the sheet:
MCU, Power, IMU, SWD
drawn by: Andreea Radu
LiPo Charger
DC/DC
IMU
DEC1
DEC4_6
DEC3
P0.00/XL1
P0.01/XL2
SWD

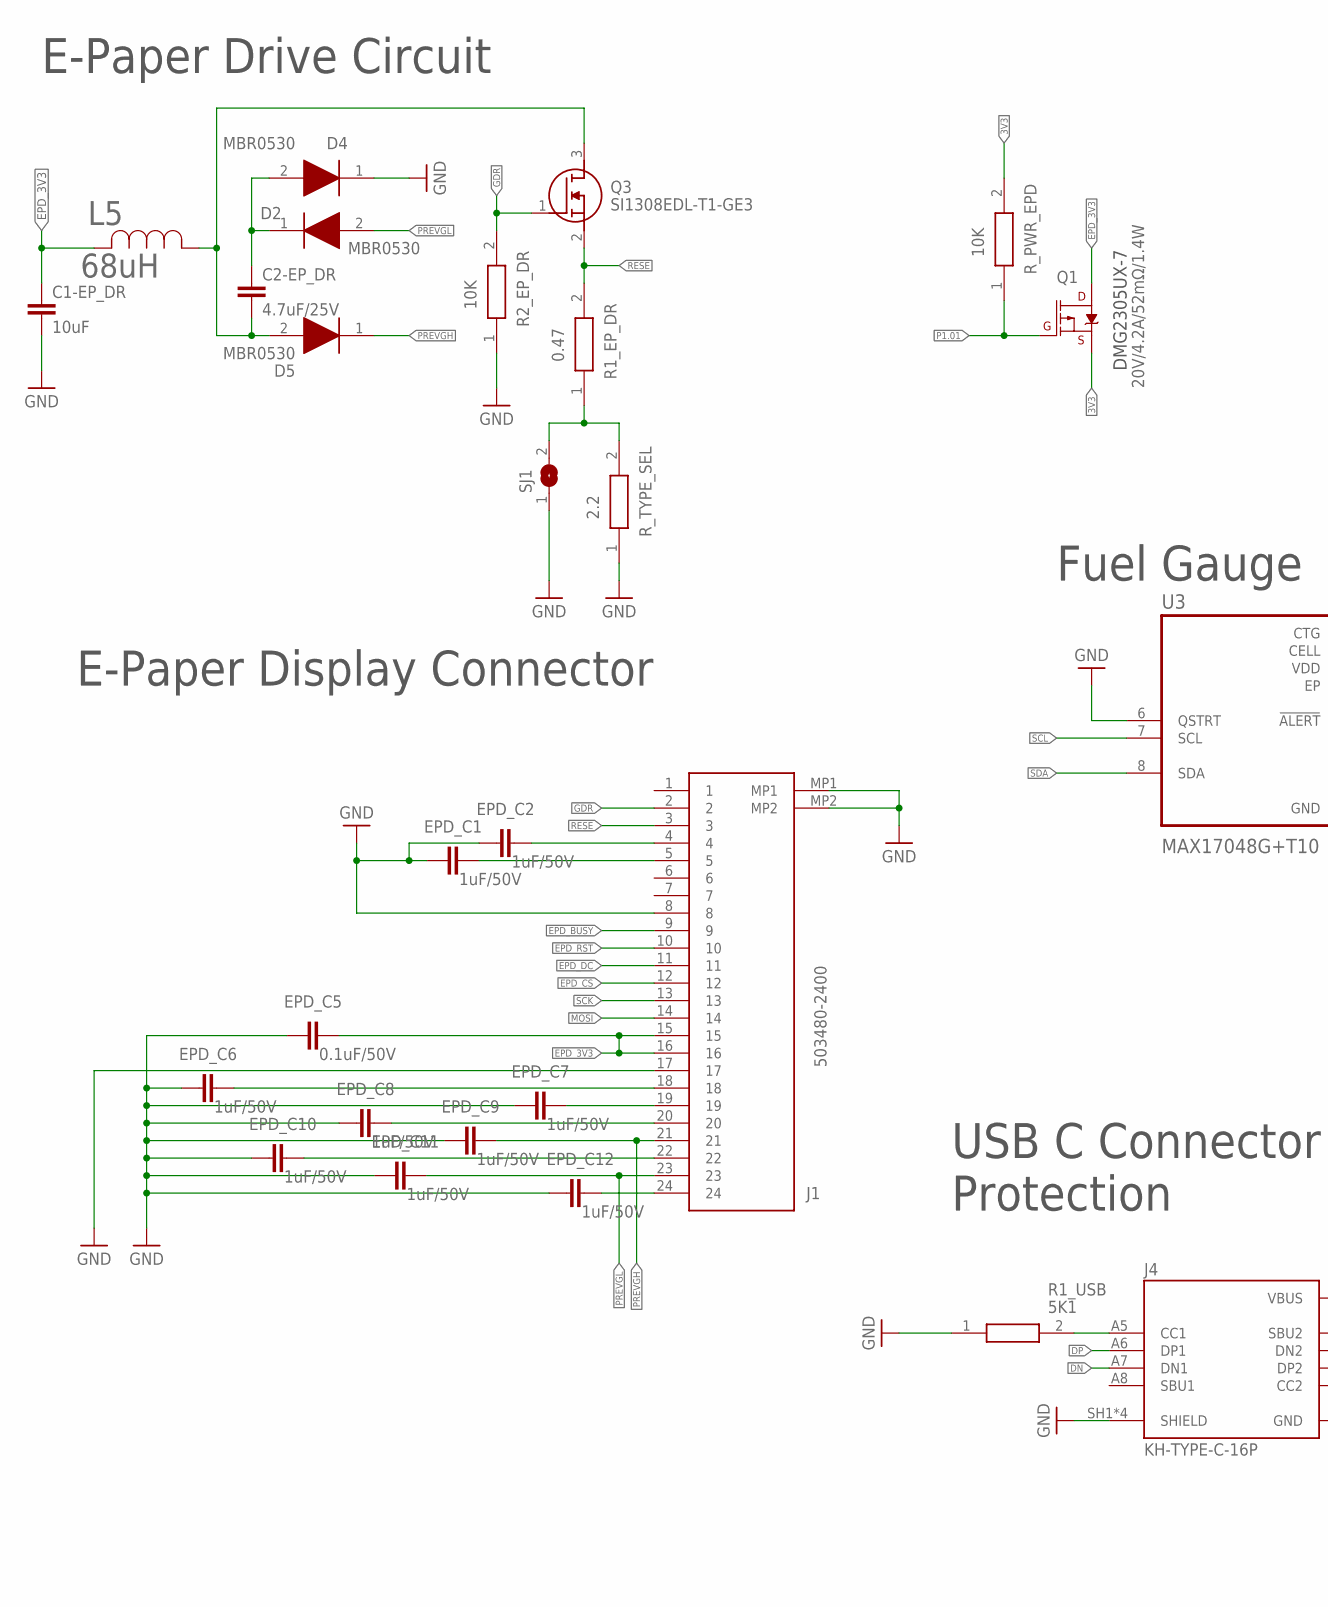
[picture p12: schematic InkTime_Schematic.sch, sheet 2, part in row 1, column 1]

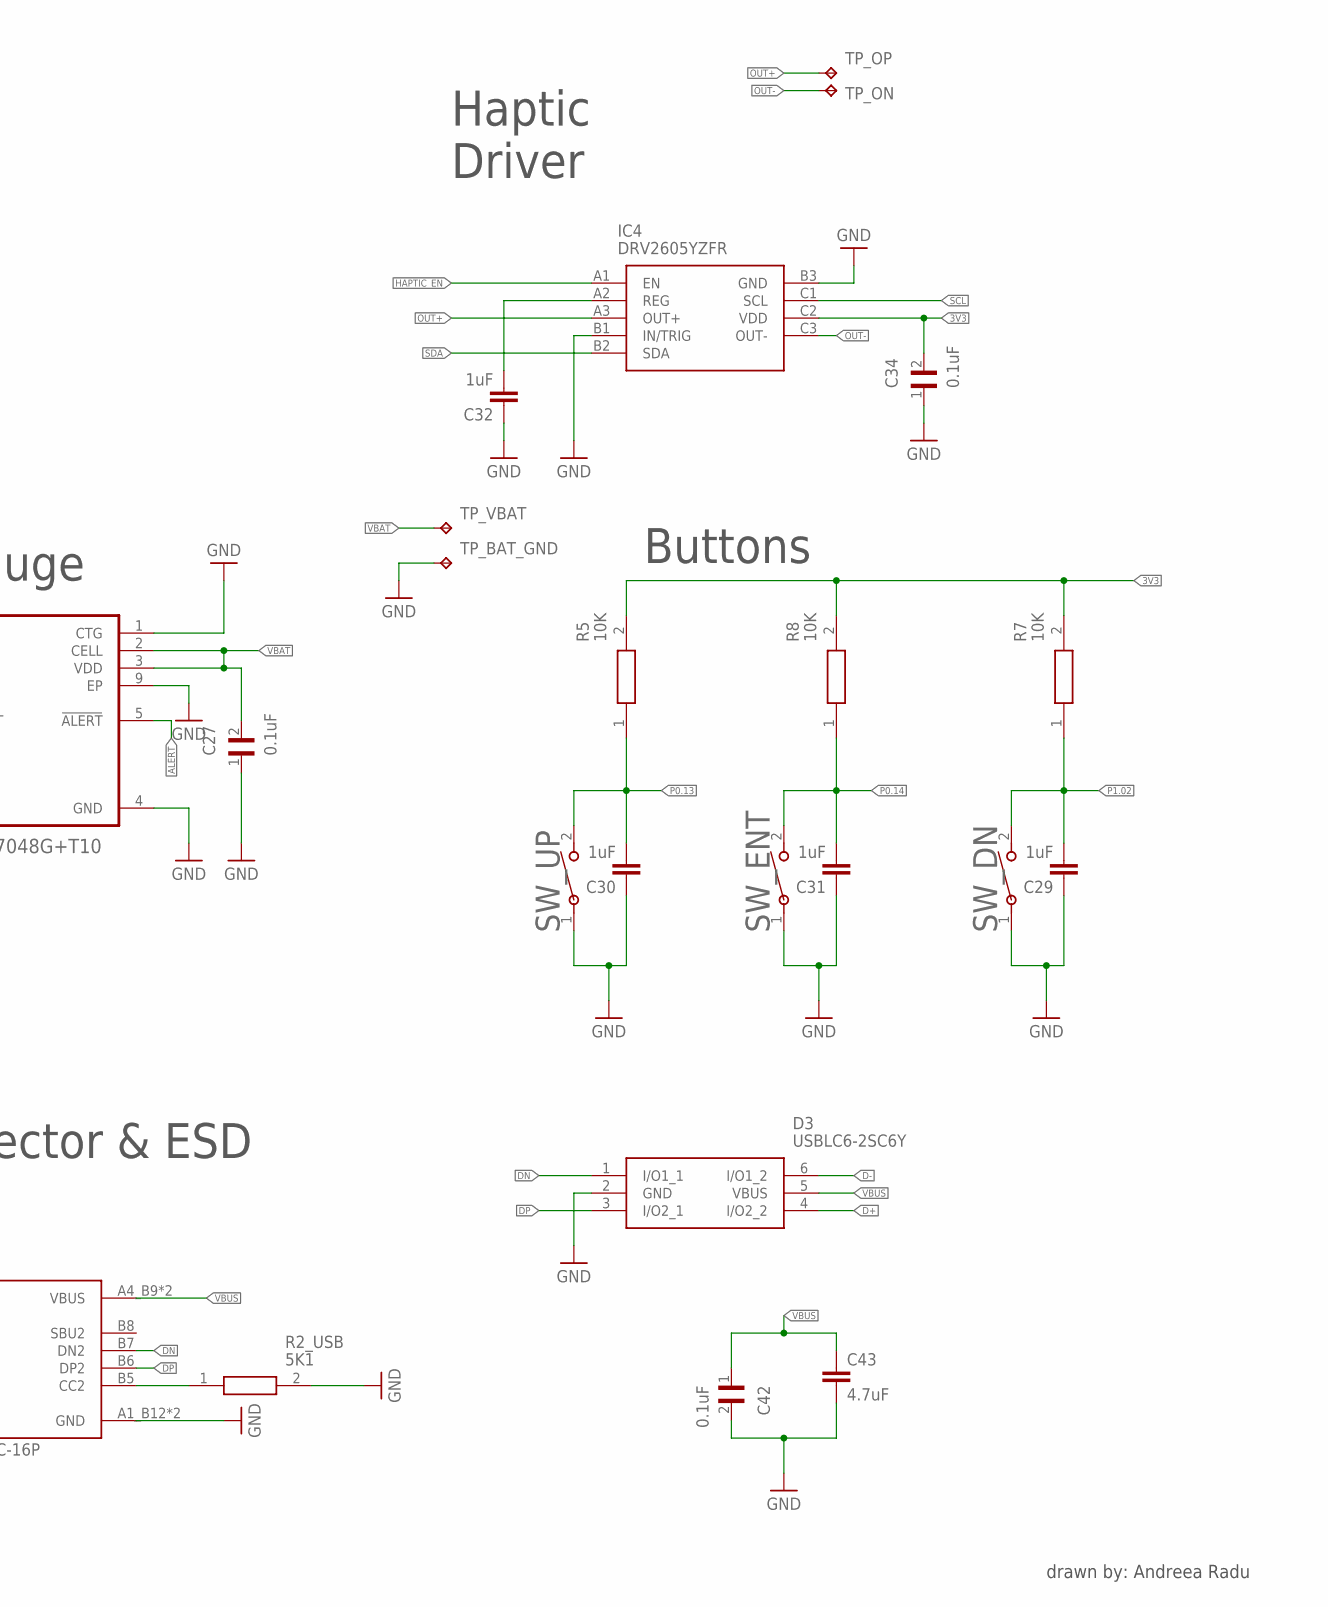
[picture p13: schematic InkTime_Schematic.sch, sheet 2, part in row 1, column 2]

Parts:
C1-EP_DR: 10uF; ESP32_C6_LIBRARY_1_ESP32_WROVER_EAGLE-LTSPICE_C0402
C2-EP_DR: 4.7uF/25V; ESP32_C6_LIBRARY_1_ESP32_WROVER_EAGLE-LTSPICE_C0402
C27, C34, C42: 0.1uF; GRM011R60J152KE01L_2_CAPC0201X13N
C29, C30, C31, C32: 1uF; ESP32_C6_LIBRARY_1_ESP32_WROVER_EAGLE-LTSPICE_C0402
C43: 4.7uF; ESP32_C6_LIBRARY_1_ESP32_WROVER_EAGLE-LTSPICE_C0402
D2, D4, D5: MBR0530; ESP32_C6_LIBRARY_5_SOD3716X135N
D3: USBLC6-2SC6Y; ESP32_C6_LIBRARY_3_SOT95P280X145-6N
EPD_C1, EPD_C2, EPD_C6, EPD_C7, EPD_C8, EPD_C9, EPD_C10, EPD_C11, EPD_C12: 1uF/50V; ESP32_C6_LIBRARY_1_ESP32_WROVER_EAGLE-LTSPICE_C0402
EPD_C5: 0.1uF/50V; NORDIC_NRF_3_RESC0201_L
IC4: DRV2605YZFR; DRV2605YZFR_BGA9C50P3X3_144X144X62
J1: 503480-2400; 503480-2400_5034802400
J4: KH-TYPE-C-16P; KH-TYPE-C-16P_KINGHELM_KH-TYPE-C-16P
L5: 68uH; ESP32_C6_LIBRARY_2_IND_4828-WE-TPC_WRE
Q1: 20V/4.2A/52mΩ/1.4W; ESP32_C6_LIBRARY_4_ESP32_C6_LIBRARY_4_ESP32_C6_LIBRARY_4_ES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
Q3: SI1308EDL-T1-GE3; ESP32_C6_LIBRARY_6_SOT65P210X110-3N
R1_EP_DR: 0.47; CPF0201D7K68C1_0201
R1_USB, R2_USB: 5K1; ERA-1AEB3401C_0201
R2_EP_DR: 10K; CPF0201D7K68C1_0201
R5, R7, R8: 10K; ERA-1AEB3401C_0201
R_PWR_EPD: 10K; CPF0201D7K68C1_0201
R_TYPE_SEL: 2.2; CPF0201D7K68C1_0201
SJ1: ESP32_C6_LIBRARY_7_JUMPER_SJ
SW_DN: 2025-10-22_07-23-44_LIBRARY_EVP-AKE31ASW_EVP-AKE3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; 2025-10-22_07-23-44_LIBRARY_SW_EVP-AKE31A_PAN
SW_ENT: 2025-10-22_07-23-44_LIBRARY_EVP-AKE31ASW_EVP-AKE3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; 2025-10-22_07-23-44_LIBRARY_SW_EVP-AKE31A_PAN
SW_UP: 2025-10-22_07-23-44_LIBRARY_EVP-AKE31ASW_EVP-AKE3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; 2025-10-22_07-23-44_LIBRARY_SW_EVP-AKE31A_PAN
TP_BAT_GND: HECTOR_WATCH_1_TPTP20R; HECTOR_WATCH_1_TP20R
TP_ON: HECTOR_WATCH_1_TPTP20R; HECTOR_WATCH_1_TP20R
TP_OP: HECTOR_WATCH_1_TPTP20R; HECTOR_WATCH_1_TP20R
TP_VBAT: HECTOR_WATCH_1_TPTP20R; HECTOR_WATCH_1_TP20R
U3: MAX17048G+T10; ESP32_C6_LIBRARY_SON50P200X200X80-9N

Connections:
3V3: C34.2, IC4.C2 (VDD), Q1.2 (S), R5.2, R7.2, R8.2, R_PWR_EPD.2; also elsewhere on the board
ALERT: U3.5 (!ALERT); also elsewhere on the board
D+: D3.4 (I/O2_2); also elsewhere on the board
D-: D3.6 (I/O1_2); also elsewhere on the board
DN: D3.1 (I/O1_1), J4.A7 (DN1), J4.B7 (DN2)
DP: D3.3 (I/O2_1), J4.A6 (DP1), J4.B6 (DP2)
EPD_3V3: C1-EP_DR.1, EPD_C5.2, J1.15, J1.16, L5.2, Q1.3 (D)
EPD_BUSY: J1.9; also elsewhere on the board
EPD_CS: J1.12; also elsewhere on the board
EPD_DC: J1.11; also elsewhere on the board
EPD_RST: J1.10; also elsewhere on the board
GDR: J1.2, Q3.1 (G), R2_EP_DR.2
GND: C1-EP_DR.2, C27.1, C29.1, C30.1, C31.1, C32.1, C34.1, C42.2, C43.2, D3.2 (GND), D4.1 (K), EPD_C1.1, EPD_C2.1, EPD_C5.1, EPD_C6.1, EPD_C7.1, EPD_C8.1, EPD_C9.1, EPD_C10.1, EPD_C11.1, EPD_C12.1, IC4.B1 (IN/TRIG), IC4.B3 (GND), J1.8, J1.17, J1.MP1, J1.MP2, J4.A1_B12 (GND), J4.A12_B1 (GND), J4.SH1 (SHIELD), J4.SH2 (SHIELD), J4.SH3 (SHIELD), J4.SH4 (SHIELD), R1_USB.1, R2_EP_DR.1, R2_USB.2, R_TYPE_SEL.1, SJ1.1, SW_DN.1, SW_ENT.1, SW_UP.1, TP_BAT_GND.TP, U3.1 (CTG), U3.4 (GND), U3.6 (QSTRT), U3.9 (EP); also elsewhere on the board
HAPTIC_EN: IC4.A1 (EN); also elsewhere on the board
MOSI: J1.14; also elsewhere on the board
unnamed: C2-EP_DR.1, D2.1 (K), D4.2 (A)
unnamed: C2-EP_DR.2, D5.2 (A), L5.1, Q3.3 (D)
unnamed: R1_EP_DR.1, R_TYPE_SEL.2, SJ1.2
unnamed: C32.2, IC4.A2 (REG)
unnamed: EPD_C2.2, J1.4
unnamed: EPD_C1.2, J1.5
unnamed: EPD_C6.2, J1.18
unnamed: EPD_C7.2, J1.19
unnamed: EPD_C8.2, J1.20
unnamed: EPD_C10.2, J1.22
unnamed: EPD_C12.2, J1.24
unnamed: J4.A5 (CC1), R1_USB.2
unnamed: J4.B5 (CC2), R2_USB.1
OUT+: IC4.A3 (OUT+), TP_OP.TP
OUT-: IC4.C3 (OUT-), TP_ON.TP
P0.13: C30.2, R5.1, SW_UP.2; also elsewhere on the board
P0.14: C31.2, R8.1, SW_ENT.2; also elsewhere on the board
P1.01: Q1.1 (G), R_PWR_EPD.1; also elsewhere on the board
P1.02: C29.2, R7.1, SW_DN.2; also elsewhere on the board
PREVGH: D5.1 (K), EPD_C9.2, J1.21
PREVGL: D2.2 (A), EPD_C11.2, J1.23
RESE: J1.3, Q3.2 (S), R1_EP_DR.2
SCK: J1.13; also elsewhere on the board
SCL: IC4.C1 (SCL), U3.7 (SCL); also elsewhere on the board
SDA: IC4.B2 (SDA), U3.8 (SDA); also elsewhere on the board
VBAT: C27.2, TP_VBAT.TP, U3.2 (CELL), U3.3 (VDD); also elsewhere on the board
VBUS: C42.1, C43.1, D3.5 (VBUS), J4.A4_B9 (VBUS), J4.A9_B4 (VBUS); also elsewhere on the board

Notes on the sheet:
drawn by: Andreea Radu
E-Paper Drive Circuit
DMG2305UX-7
Haptic Driver
E-Paper Display Connector
Fuel Gauge
Buttons
USB C Connector & ESD Protection

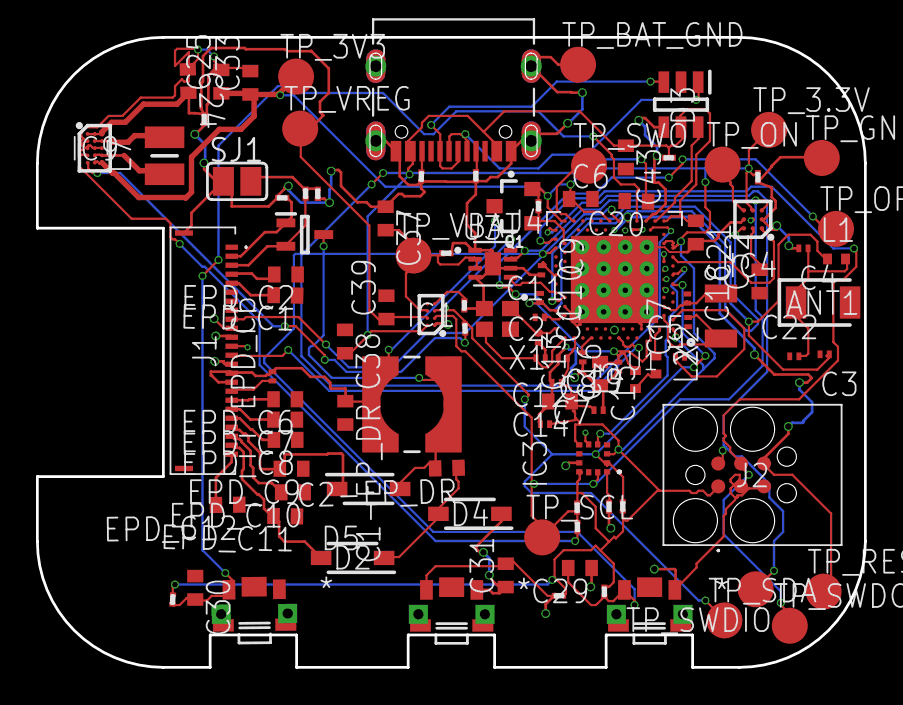
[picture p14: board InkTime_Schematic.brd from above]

Board: 4 copper layers, 46.0 x 35.0 mm, 105 parts (0 on the bottom side), 70 nets.

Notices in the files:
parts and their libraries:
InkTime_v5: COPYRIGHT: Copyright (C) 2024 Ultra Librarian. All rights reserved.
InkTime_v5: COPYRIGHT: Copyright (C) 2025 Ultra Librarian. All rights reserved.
